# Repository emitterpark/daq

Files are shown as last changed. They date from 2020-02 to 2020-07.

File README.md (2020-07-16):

**DAQ**, Kolaylıkla **IoT (Nesnelerin İnterneti)** projelerinizi
yapabileceğiniz, LoRaWAN kablosuz ağlarıyla uyumlu bir **sensör
aktarıcısıdır**. Üzerindeki **Analog ve Dijital** girişlerine çok
çeşitli sensörleri bağlayabilir, **kilometrelerce** mesafelerden
**kablosuz** yolla bilgi toplayabilirsiniz.

Endüstride mevcut **makineleri** **IoT uyumlu** hale
dönüştürebilirsiniz.

**Akıllı Şehir, Kampüs, Endüstri, Tarım, Otel** ve benzer IoT projenizin
merkezinde **internete** bağlanmış olan bir **LoRaWAN Gateway** cihazı
bulunur. Projenizdeki çok sayıda **DAQ** ünitelerinizden gelen veriler
buradan paketlenerek internete servis edilir. Kendinize ait veya **Açık
kullanım** özelliğindeki diğer kurulu olan LoRaWAN Gateway
cihazlarındanve istasyonlardan faydalanabilirsiniz.

**DAQ** üniteleri, baştan-sona, **The Things Network (TTN)** ve
**myDevices Cayenne** adlı **ücretsiz**

**veri görüntüleme uygulaması** ile tam uyumludur. Uygulamayı indirip
kurduğunuz **PC** ve **Mobil** cihazlarınızda, ünitelerinizden gelen
verileri **zengin görsellerden** takip edebilir, **geçmiş verilere**
erişebilir, **alarm ve uyarıları** bekleyebilirsiniz. Diğer platformlara
kolayca yönlendirebilirsiniz.

LoRaWAN standardı, **ISM** bantlarında, mevcut WiFi, ZigBee, FSK
standartlarına göre daha düşük güçle ve uzak mesafelerde çalışan
kablosuz sensörlerin yapımını mümkün kılar. IP tabanlı olmayıp; **cihaz
kimliği**, uygulama kimliği ve kripto güvenlik anahtarı ile sensörlerin
**IoT platformlarında** takibi için beklenen **esnekliğe ve güvenliğe**
sahiptir.

IoT projeleriniz için **DAQ** ünitelerini, Gateway cihazını ve çeşitli
Analog ve Dijital sensörleri
[[www.example.com]{.ul}](http://www.example.com/) web mağzamızdan satın
alabilirsiniz.

Ürünlerin başlangıç ayarları yapılmış olup **Tak-Çalıştır** özelliği ile
kullanıma hazırdır.

**( Türkiye EU868 MHz )**

**ÖZELLİKLER**

**2 Kanal Analog sensör girişi**

4-20ma endüstriyel otomasyon standardı

Diferansiyel, 16 bit çözünürlük

High ve Low taraf ölçüm yapabilme

Düşük ölçüm direnci, 50 Ohm (Max. 1V gerilim düşümü)

Giriş ölçeklendirme

Sıcaklık, nem, basınç, pozisyon vb. 14 farklı birim tanımlama

Yüksek ve düşük alarm seviyeleri ve kalma süreli histeresis

Aşırı voltaj ve elektrostatik koruma

**2 Kanal Dijital sinyal girişi**

3-24V High seviye

3 farklı dijital birim tanımlama

Dijital alarm ve kalma süreli histeresis

Optoelektronik izolasyon

**5-24V DC endüstriyel besleme girişi**

Dahili 3.3V DC-DC buck dönüştürücü

Alıcı 60mW, Verici 360mW(anlık) güç tüketimi

**Endüstriyel ortama uygun fiziksel tasarım**

Geçmeli tip vidalı klemens girişi

USB micro B konnektör

Aksiyon ledi

Reset butonu

3dbi harici anten

Montaj kulaklı, boyalı alüminyum kutu

24(h)x60(w)x70(l) mm

**Kolay kurulum**

Tak-Çalıştır özelliği, TTN (The Things Network) ve myDevices Cayenne

USB ile PC ve mobil cihazdan parametre ayarlama imkanı

Rapor süresi, alarm seviyeleri, cihaz kimliği, kablosuz çalışma
parametreleri ve diğerleri

**LoRaWAN kablosuz ağ**

LoRaWAN Class A

Lisans gerektirmeyen ISM Bant (EU868, US915, AU915, AS923, IN865, KR920)

20dbm (100mW) radyo verici çıkış gücü

-148dbm radyo alıcı hassasiyeti

Şehir içi 3Km, Şehir dışı 15Km'ye kadar çalışma mesafesi

DevEUI, AppEUI, AppKEY ile OTAA aktivasyonu

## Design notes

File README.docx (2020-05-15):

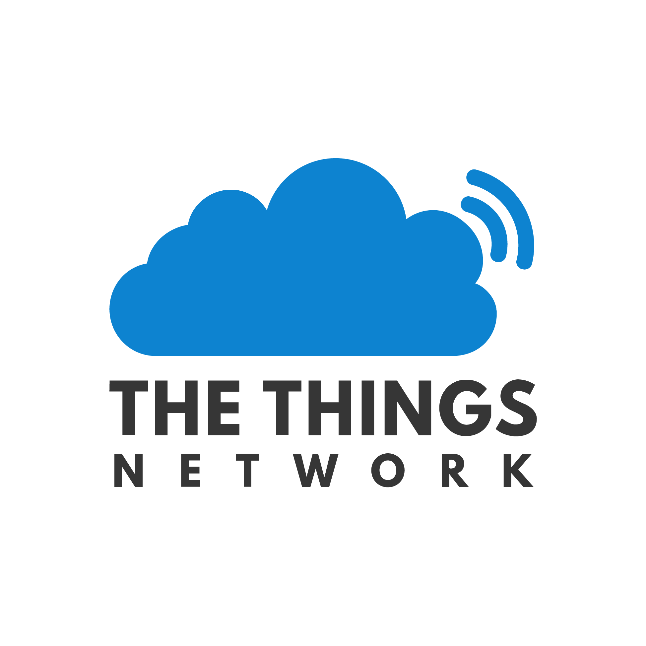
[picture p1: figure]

myDevices

Cayenne

3km Şehir İçi

15km Şehir dışı

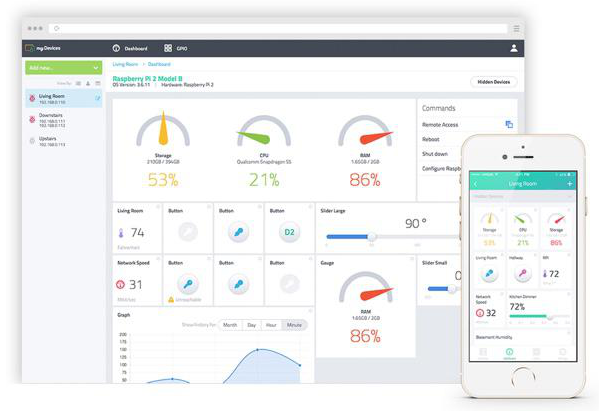
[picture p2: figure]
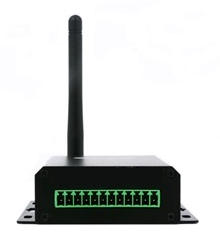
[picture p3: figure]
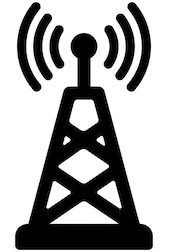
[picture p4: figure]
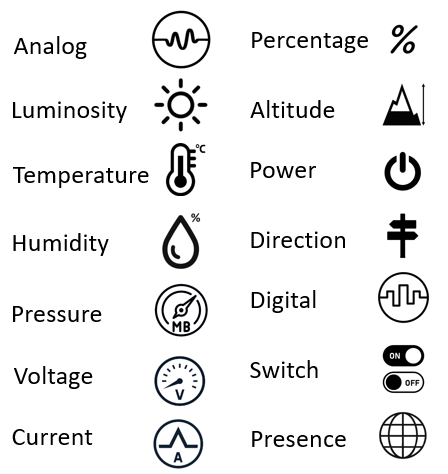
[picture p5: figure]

DAQ

2 X

4-20 ma

Giriş

2 X

Dijital

Giriş

DAQ, Kolaylıkla IoT (Nesnelerin İnterneti) projelerinizi yapabileceğiniz, LoRaWAN kablosuz ağlarıyla uyumlu bir sensör aktarıcısıdır. Üzerindeki Analog ve Dijital girişlerine çok çeşitli sensörleri bağlayabilir, kilometrelerce mesafelerden kablosuz yolla bilgi toplayabilirsiniz.

Endüstride mevcut makineleri IoT uyumlu hale dönüştürebilirsiniz.

Akıllı Şehir, Kampüs, Endüstri, Tarım, Otel ve benzer IoT projenizin merkezinde internete bağlanmış olan bir LoRaWAN Gateway cihazı bulunur. Projenizdeki çok sayıda DAQ ünitelerinizden gelen veriler buradan paketlenerek internete servis edilir. Kendinize ait veya Açık kullanım özelliğindeki diğer kurulu olan LoRaWAN Gateway cihazlarındanve istasyonlardan faydalanabilirsiniz.

DAQ üniteleri, baştan-sona, The Things Network (TTN) ve myDevices Cayenne adlı ücretsiz

veri görüntüleme uygulaması ile tam uyumludur. Uygulamayı indirip kurduğunuz PC ve Mobil cihazlarınızda, ünitelerinizden gelen verileri zengin görsellerden takip edebilir, geçmiş verilere erişebilir, alarm ve uyarıları bekleyebilirsiniz. Diğer platformlara kolayca yönlendirebilirsiniz.

LoRaWAN standardı, ISM bantlarında, mevcut WiFi, ZigBee, FSK standartlarına göre daha düşük güçle ve uzak mesafelerde çalışan kablosuz sensörlerin yapımını mümkün kılar. IP tabanlı olmayıp; cihaz kimliği, uygulama kimliği ve kripto güvenlik anahtarı ile sensörlerin IoT platformlarında takibi için beklenen esnekliğe ve güvenliğe sahiptir.

IoT projeleriniz için DAQ ünitelerini, Gateway cihazını ve çeşitli Analog ve Dijital sensörleri www.example.com web mağzamızdan satın alabilirsiniz.

Ürünlerin başlangıç ayarları yapılmış olup Tak-Çalıştır özelliği ile kullanıma hazırdır.

( Türkiye EU868 MHz )

ÖZELLİKLER

2 Kanal Analog sensör girişi

4-20ma endüstriyel otomasyon standardı

Diferansiyel, 16 bit çözünürlük

High ve Low taraf ölçüm yapabilme

Düşük ölçüm direnci, 50 Ohm (Max. 1V gerilim düşümü)

Giriş ölçeklendirme

Sıcaklık, nem, basınç, pozisyon vb. 14 farklı birim tanımlama

Yüksek ve düşük alarm seviyeleri ve kalma süreli histeresis

Aşırı voltaj ve elektrostatik koruma

2 Kanal Dijital sinyal girişi

3-24V High seviye

3 farklı dijital birim tanımlama

Dijital alarm ve kalma süreli histeresis

Optoelektronik izolasyon

5-24V DC endüstriyel besleme girişi

Dahili 3.3V DC-DC buck dönüştürücü

Alıcı 60mW, Verici 360mW(anlık) güç tüketimi

Endüstriyel ortama uygun fiziksel tasarım

Geçmeli tip vidalı klemens girişi

USB micro B konnektör

Aksiyon ledi

Reset butonu

3dbi harici anten

Montaj kulaklı, boyalı alüminyum kutu

24(h)x60(w)x70(l) mm

Kolay kurulum

Tak-Çalıştır özelliği, TTN (The Things Network) ve myDevices Cayenne

USB ile PC ve mobil cihazdan parametre ayarlama imkanı

Rapor süresi, alarm seviyeleri, cihaz kimliği, kablosuz çalışma parametreleri ve diğerleri

LoRaWAN kablosuz ağ

LoRaWAN Class A

Lisans gerektirmeyen ISM Bant (EU868, US915, AU915, AS923, IN865, KR920)

20dbm (100mW) radyo verici çıkış gücü

-148dbm radyo alıcı hassasiyeti

Şehir içi 3Km, Şehir dışı 15Km’ye kadar çalışma mesafesi

DevEUI, AppEUI, AppKEY ile OTAA aktivasyonu

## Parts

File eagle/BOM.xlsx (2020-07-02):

IC1 | 1 | ATMEGA32U4-MU | QFN-44 |  | X
IC2 | 1 | AP63201WU-7 | SOT23-6 |  | X
IC3,4 | 2 | HCPL-181-00DE (PC357N1–10) | SM MINI FLAT |  | X
IC5,6 | 2 | INA226AIDGS | VSSOP-10 |  | X
MOD1 | 1 | RAK4200 LORA MODULE EU868MHZ | SM-20 | link (https://store.rakwireless.com/products/rak4200-lora-module?variant=31767678091309) | X
D1,2,3,4 | 4 | B5817W | SOD123 |  | X
LED1 | 1 | LED RED 3MM | DIP
XT1 | 1 | CRYSTAL PASSIVE 8MHZ 4PIN | 5032 |  | X
F1 | 1 | PTC RESETTABLE FUSE 0.5A | 1206 |  | X
SW1 | 1 | PUSH BUTTON TACTILE SWITCH 6X6X9MM R/A | DIP | link (https://www.aliexpress.com/item/32901481925.html)
CON1 | 1 | HEADER MALE 2.54MM 6P 2R | DIP
CON2 | 1 | HEADER MALE 2.54MM 8P 2R | DIP
CON3 | 1 | CONNECTOR RF SMA R/A FEMALE 20MM | DIP | link (https://www.aliexpress.com/item/33001356841.html?spm=a2g0o.detail.1000023.2.57702e34zxfXmB)
CON4 | 1 | STANDARD MICRO B USB FEMALE CONNECTOR | SM |  | X
CON5 | 1 | (KF2EDGR)15EDGRC-3.81-10P (HEADER RA) + (KF2EDGK)15EDGK-3.81-10P (PLUG) | DIP
L1 | 1 | CDRH127R 10UH INDUCTOR 12X12MM SHIELDED | SM
L2,3 | 2 | MMZ2012Y152B FERRITE BEAD | 0805 |  | X ?????
C1,8,21,22,27,32 | 6 | 10UF X5R/X7R | 0603 |  | X
C2,5,7,10,12,15,16,18,19,20,23,24,25,26,31 | 15 | 100NF X5R/X7R | 0603 |  | X
C3,4 | 2 | 22PF X5R/X7R | 0603 |  | X
C6,28,29,30,33,34,35 | 7 | 1UF X5R/X7R | 0603 |  | X
C9,13,14 | 3 | 22UF X7R | 1206 |  | X
C11 | 1 | 100PF X5R/X7R | 0603 |  | X
C17 | 1 | 100UF 8MM | SM |  | X
R1,2 | 2 | 22R 5% | 0603 |  | X
R3,8,10,12,14,16,17,22,27,28 | 10 | 10K 5% | 0603 |  | X
R4 | 1 | 220R 5% | 0603 |  | X
R5 | 1 | 115K 1% (120K) (110K) | 0603 |  | X
R6 | 1 | 33K 1% (36K) (33K) | 0603 |  | X
R7,9,11 | 3 | 100R 5% | 0603 |  | X
R13,15 | 2 | 2K2 5% | 0805 |  | X
R18,23 | 2 | 3.9R 1% | 0805 |  | X
R19,20,24,25 | 4 | 50R 1% | 0805 |  | X ?????
R21,26 | 2 | 10R 5% | 0603 |  | X
ANTENNA | 1 | 868MHZ 5DBI SMA-MALE WHIP |  | link (https://www.aliexpress.com/item/32921464471.html?spm=2114.12010612.8148356.36.3e3f1f0b2ckfAt)
ALUMINUM ENCLOSURE | 1 | AK-C-A16 24(H)X80(W)X90(L) MM CUSTOM 68.7(L) MM |  | link (https://www.aliexpress.com/item/1585694309.html)
PCB | 1 | FR4 1.6MM 1ozCu 59.7(W)X68.6(L) MM (2350X2700MIL)
LAZER CUTTING

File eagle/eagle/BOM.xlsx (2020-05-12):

IC1 | 1 | ATMEGA32U4-MU | QFN-44
IC2 | 1 | AP63201WU-7 | SOT23-6 | AP63200 OLD
IC3,4 | 2 | HCPL-181-00DE (PC357N1–10) | SM MINI FLAT | link (https://www.aliexpress.com/item/32909119073.html?spm=2114.12010615.8148356.4.657bf361XrP6RL)
IC5,6 | 2 | INA226AIDGS | VSSOP-10 | link (http://www.aliexpress.com/item/33021667752.html?spm=2114.12010615.8148356.2.31ef2adf4GEmzi)
MOD1 | 1 | RAK4200 LORA MODULE EU868MHZ | SM-20 | link (https://store.rakwireless.com/products/rak4200-lora-module?variant=31767678091309)
D1,2,3,4 | 4 | B5817W | SOD123 | REFERENCE
LED1 | 1 | LED RED 3MM | DIP
XT1 | 1 | CRYSTAL PASSIVE 8MHZ 4PIN | 5032 | link (https://www.aliexpress.com/item/33010692278.html?spm=2114.12010615.8148356.8.e30c5802x90R2k)
F1 | 1 | PTC RESETTABLE FUSE 0.5A | 1206 | link (https://www.aliexpress.com/item/32876140005.html?spm=2114.12010615.8148356.3.5236158aukLNWK)
SW1 | 1 | PUSH BUTTON TACTILE SWITCH 6X6X9MM R/A | DIP | link (https://www.aliexpress.com/item/32901481925.html)
CON1 | 1 | HEADER MALE 2.54MM 6P 2R | DIP
CON2 | 1 | HEADER MALE 2.54MM 8P 2R | DIP
CON3 | 1 | CONNECTOR RF SMA R/A EOCT-WF1320 57001579 | DIP | link (https://www.aliexpress.com/item/33050835786.html)
CON4 | 1 | STANDARD MICRO B USB FEMALE CONNECTOR | SM
CON5 | 1 | (KF2EDGR)15EDGRC-3.81-10P (HEADER RA) + (KF2EDGK)15EDGK-3.81-10P (PLUG) | DIP
L1 | 1 | CDRH127R 6.8UH INDUCTOR 12X12MM SHIELDED | SM
L2,3 | 2 | MMZ2012Y152B FERRITE BEAD | 0805 | (150R @100MHZ) REFERENCE
C1,8,21,22,27,30 | 5 | 10UF X5R/X7R | 0603
C2,5,7,10,12,15,16,18,19,20,23,24,25,26,28,29,31 | 12 | 100NF X5R/X7R | 0603
C3,4 | 2 | 22PF X5R/X7R | 0603
C6, | 3 | 1UF X5R/X7R | 0603
C9,13,14 | 3 | 22UF X7R | 1206
C11 | 1 | 100PF X5R/X7R | 0603
C17 | 1 | 100UF 8MM | SM
R1,2 | 2 | 22R 5% | 0603
R3,8,10,12,14,16,17,24,31,32 | 10 | 10K 5% | 0603
R4 | 1 | 220R 5% | 0603
R5 | 1 | 115K 1% (120K) (110K) | 0603
R6 | 1 | 33K 1% (36K) (33K) | 0603
R7,9,11 | 3 | 100R 5% | 0603
R13,15 | 2 | 2K2 5% | 0805
R18,20,25,27 | 4 | 10R 1% | 0603
R19,26 | 2 | 3.3R 1% | 0805
R21,22,28,29 | 4 | 50R 1% | 0805
R23,30 | 2 | 10R 5% | 0603
ANTENNA | 1 | 868MHZ 5DBI SMA-MALE WHIP |  | link (https://www.aliexpress.com/item/32921464471.html?spm=2114.12010612.8148356.36.3e3f1f0b2ckfAt)
ALUMINUM ENCLOSURE | 1 | AK-C-A16 24(H)X80(W)X90(L) MM COLOR BLUE CUSTOM 68.7(L) MM |  | angie@szomk.com.cn
PCB | 1 | FR4 1.6MM 1ozCu 59.7(W)X65.4(L) MM (2350X2575MIL)

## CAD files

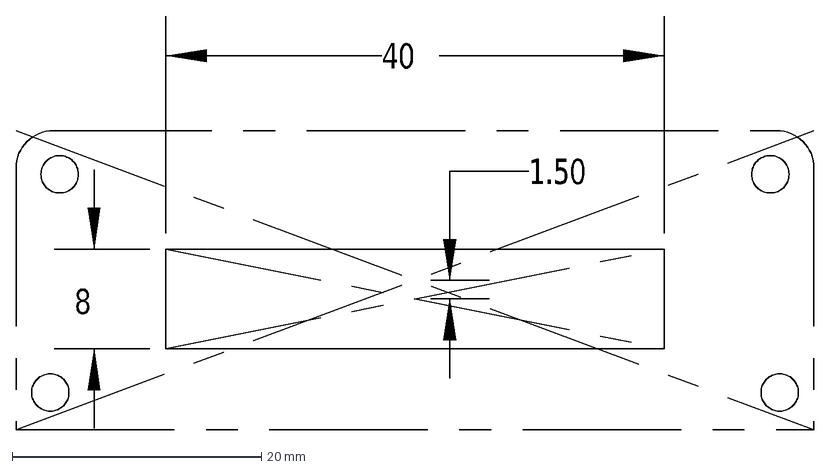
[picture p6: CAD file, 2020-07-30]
physical/eng/rear panel.DXF
1.50
40
8

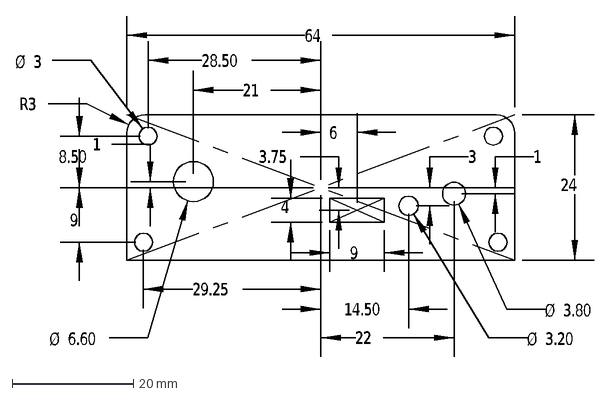
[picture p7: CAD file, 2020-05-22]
physical/ön kapak.DXF
64
24
21
1
Ø
6.60
3.20
14.50
3
3.80
22
3.75
6
9
4
R3
28.50
8.50
29.25

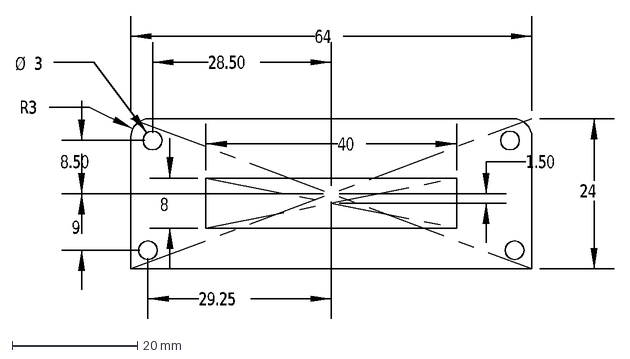
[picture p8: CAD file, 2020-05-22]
physical/arka kapak.DXF
64
24
R3
28.50
8.50
29.25
9
Ø
3
1.50
40
8

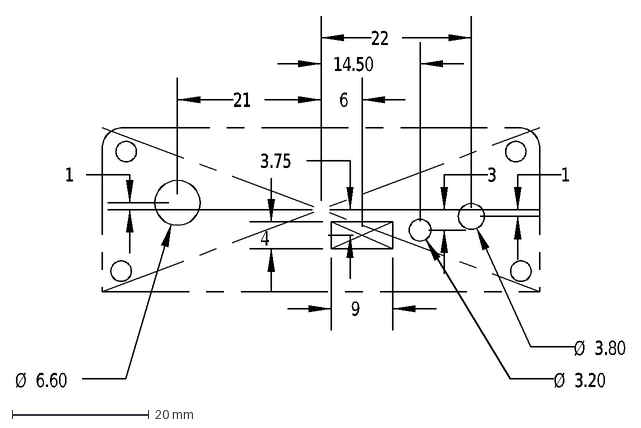
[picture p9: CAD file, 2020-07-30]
physical/eng/front panel.DXF
21
1
Ø
6.60
3.20
14.50
3
3.80
22
3.75
6
9
4

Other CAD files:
physical/arka kapak.DWG
physical/arka kapak.SLDDRW
physical/eng/front panel.DWG
physical/eng/front panel.SLDDRW
physical/eng/rear panel.DWG
physical/eng/rear panel.SLDDRW
physical/ön kapak.DWG
physical/ön kapak.SLDDRW

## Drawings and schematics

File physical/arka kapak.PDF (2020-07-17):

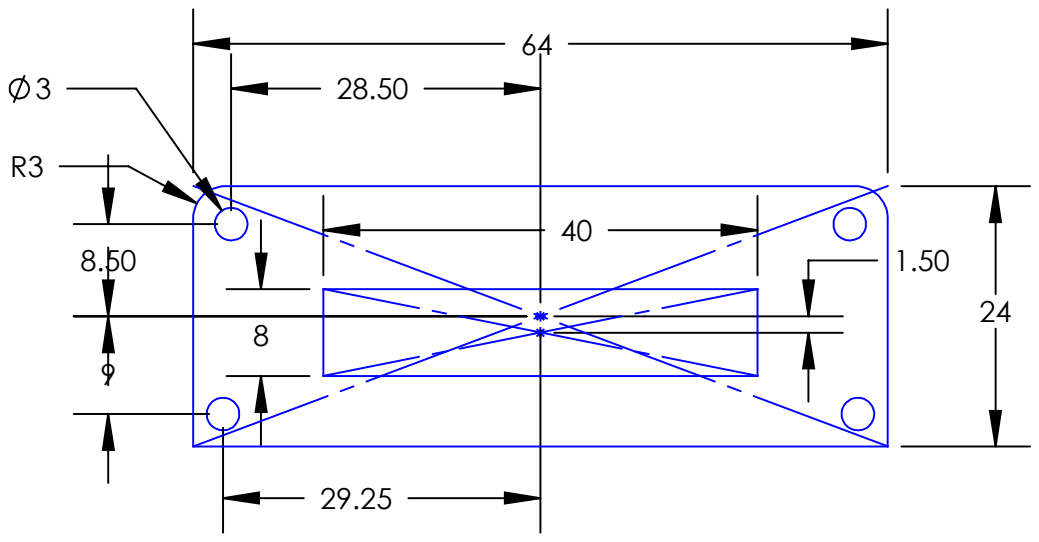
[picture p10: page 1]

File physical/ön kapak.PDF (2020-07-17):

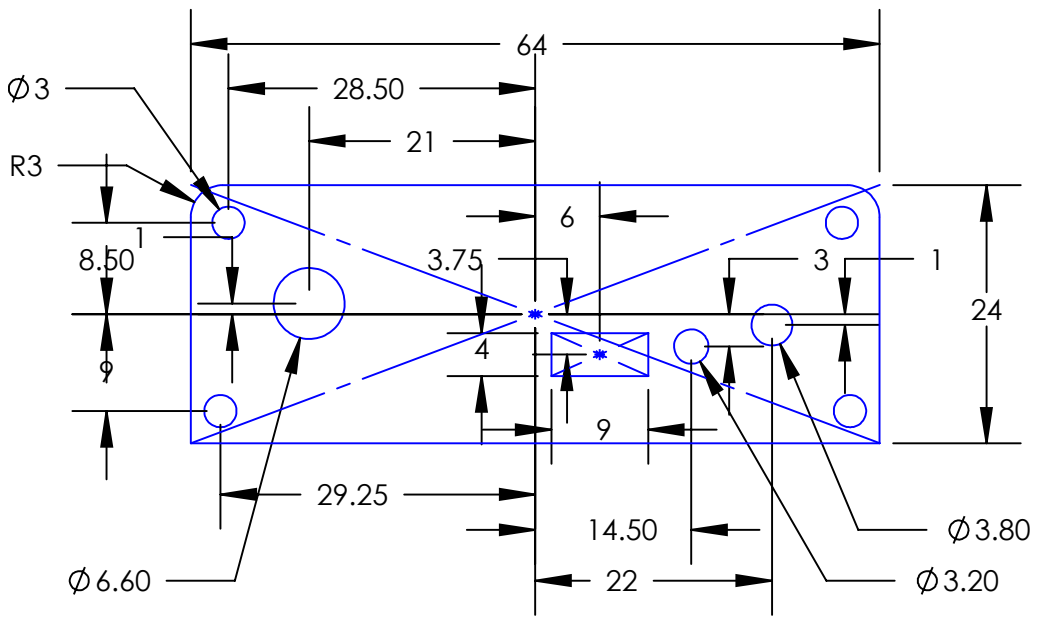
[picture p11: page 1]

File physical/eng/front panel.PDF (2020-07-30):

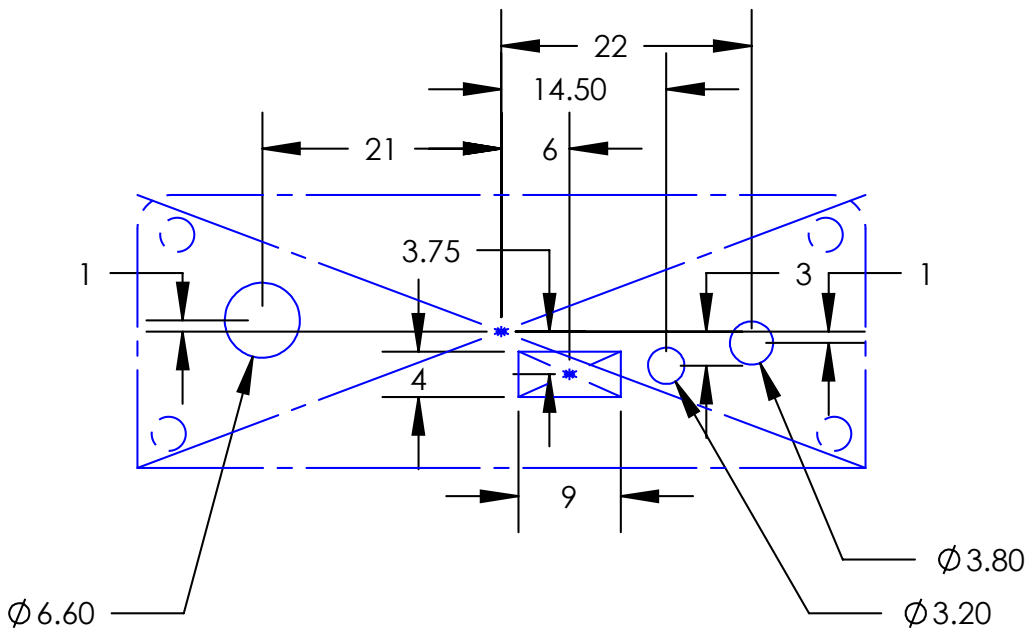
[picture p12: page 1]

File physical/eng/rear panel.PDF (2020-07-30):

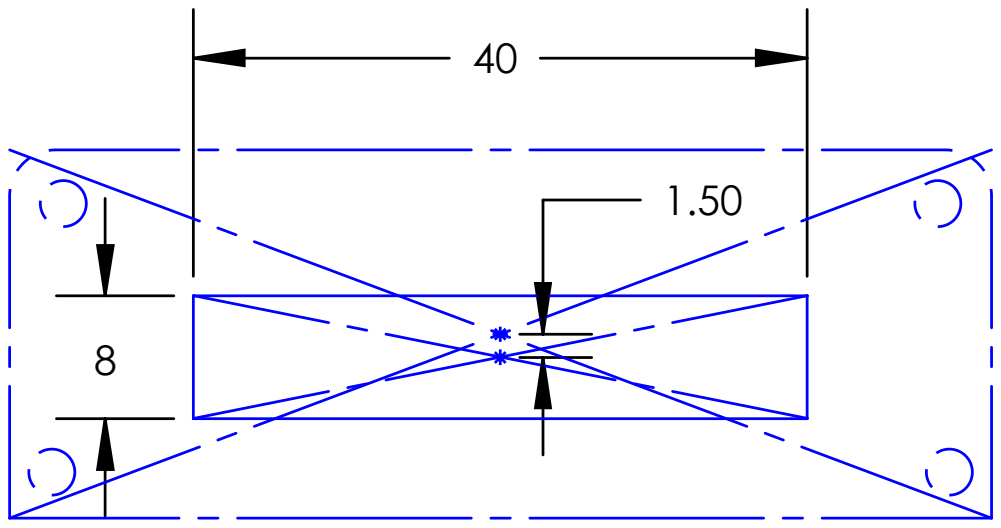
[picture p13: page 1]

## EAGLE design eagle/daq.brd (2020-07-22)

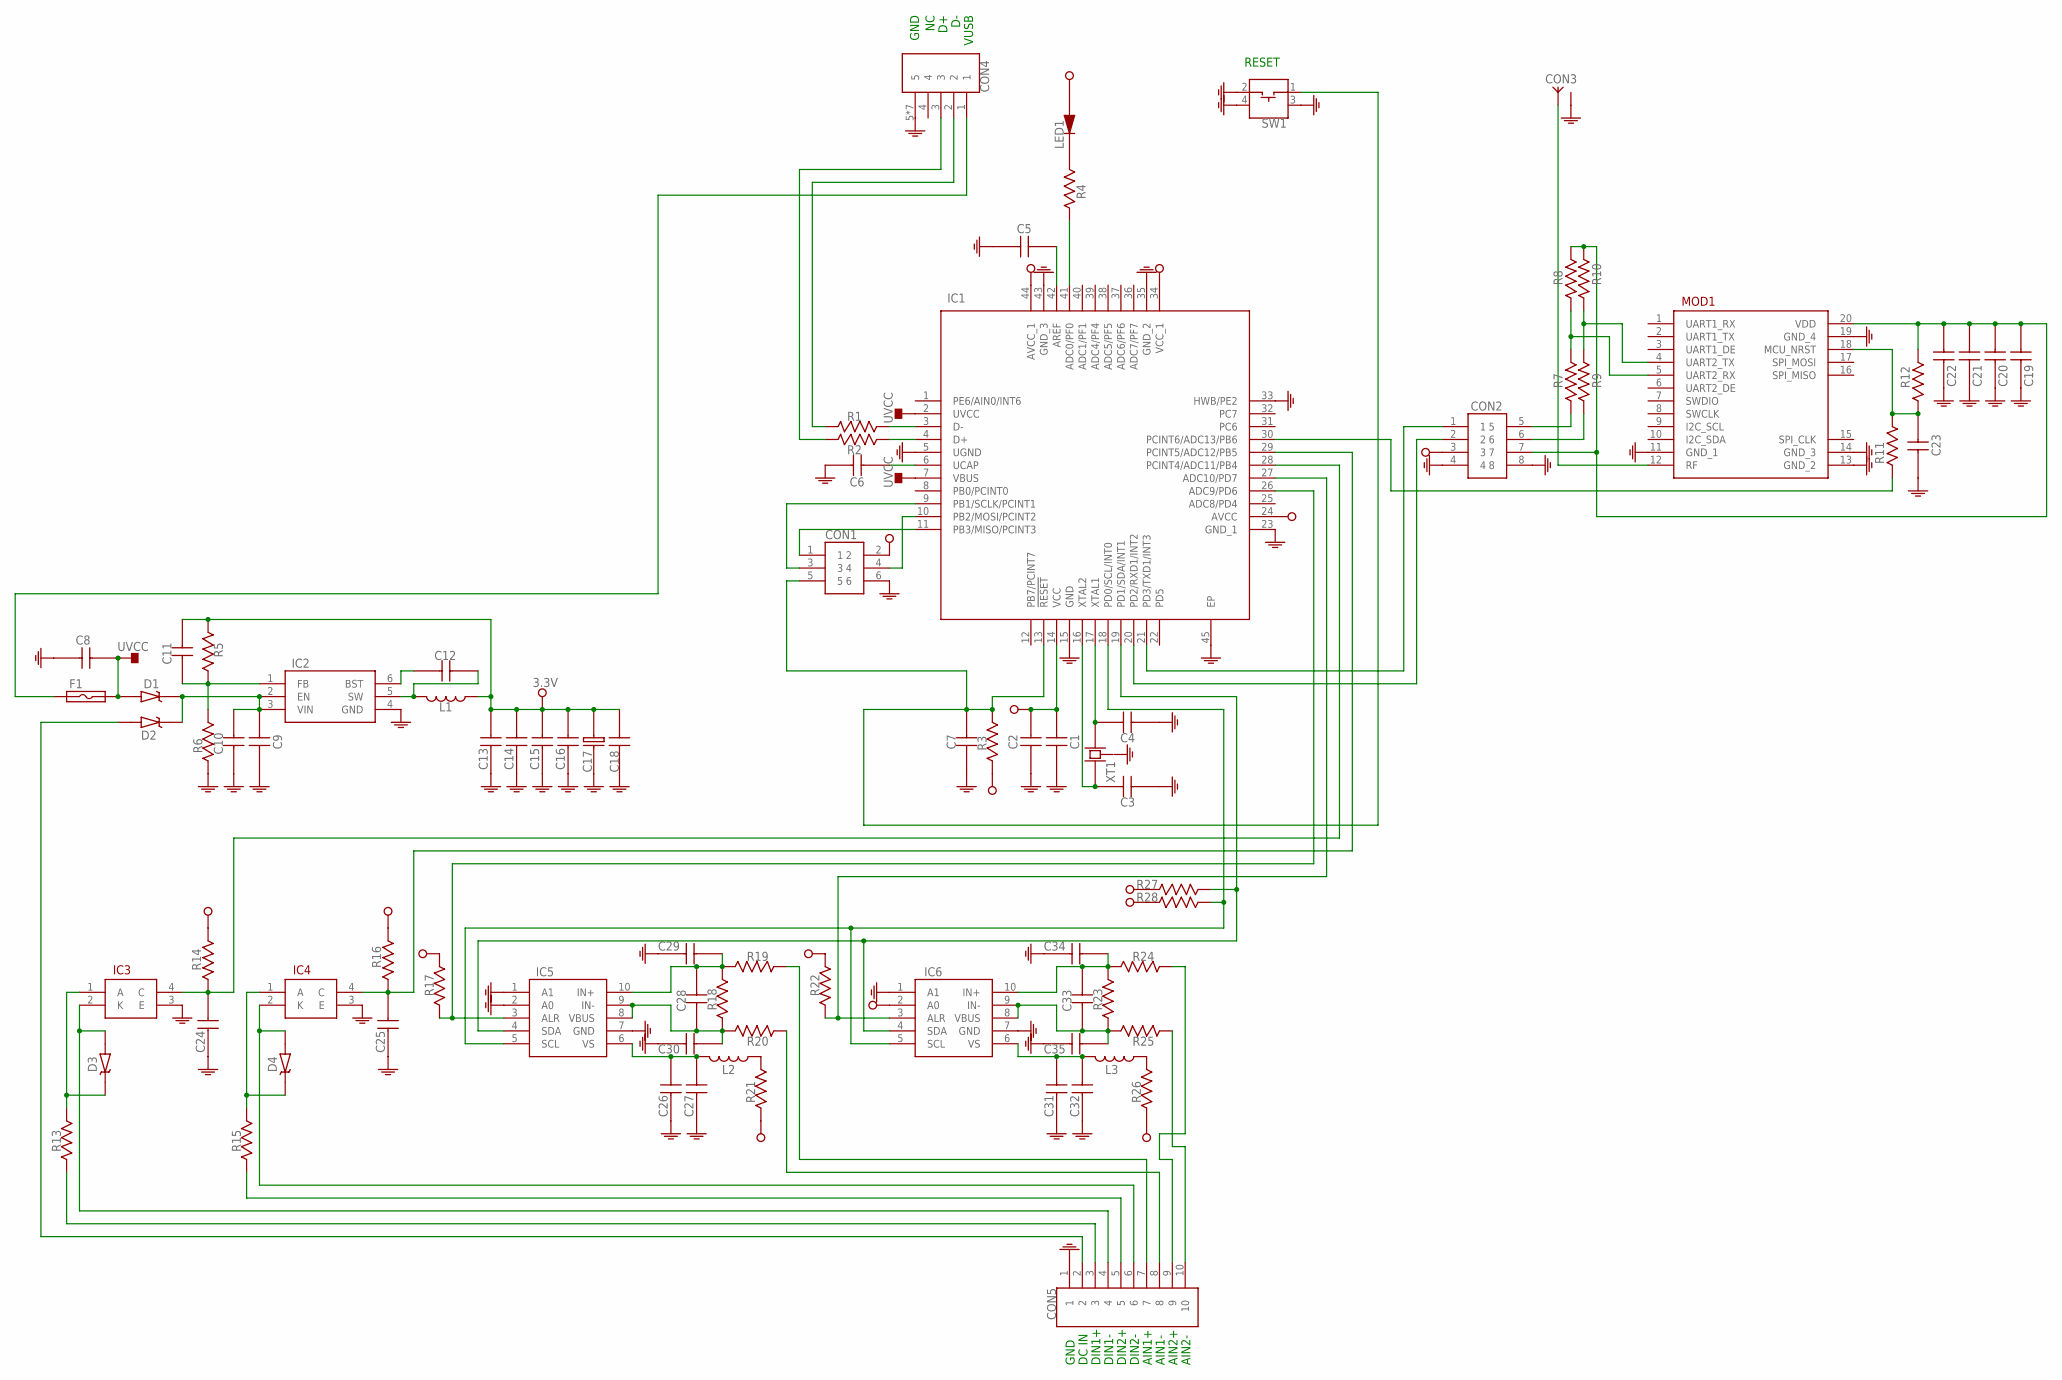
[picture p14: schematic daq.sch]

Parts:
C1, C2, C3, C4, C5, C6, C7, C8, C10, C11, C12, C15, C16, C18, C19, C20, C21, C22, C23, C24, C25, C26, C27, C28, C29, C30, C31, C32, C33, C34, C35: CAPACITOR-0603; 0603
C9, C13, C14: CAPACITOR-1206; 1206
C17: CAPACITOR-SMD-8
CON1: ISP
CON2: HEADER-8P-2R-DIP-2_54MM
CON3: SMA-RF
CON4: USB-MICRO-B-SMD
CON5: 15EDGRC-3.81-10P
D1, D2, D3, D4: DIODE-SCHOTTKY; SOD123-DIODE
F1: FUSE-1206; 1206
IC1: ATMEGA32U4-MU; QFN-44
IC2: AP63200; SOT23-6
IC3, IC4: OPTO-SMD
IC5, IC6: INA226; VSSOP-10
L1: INDUCTOR-CDRH127R
L2, L3: INDUCTOR-0805; 0805
LED1: LED-3MM-RA
MOD1: RAK4200
R1, R2, R3, R4, R5, R6, R7, R8, R9, R10, R11, R12, R14, R16, R17, R21, R22, R26, R27, R28: RESISTOR-0603; 0603
R13, R15, R18, R19, R20, R23, R24, R25: RESISTOR-0805; 0805
SW1: B3F-3150-52-55
XT1: CRYSTAL-5032-4P

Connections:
GND: C1.1, C2.1, C3.1, C4.1, C5.1, C6.1, C7.1, C8.1, C9.1, C10.1, C13.1, C14.1, C15.1, C16.1, C17.1, C18.1, C19.1, C20.1, C21.1, C22.1, C23.1, C24.1, C25.1, C26.1, C27.1, C29.2, C30.2, C31.1, C32.1, C34.2, C35.2, CON1.6, CON2.4, CON2.8, CON3.2 (GND), CON3.3 (GND), CON3.4 (GND), CON3.5 (GND), CON4.5, CON4.6 (5), CON4.7 (5), CON4.8 (5), CON4.9 (5), CON4.10 (5), CON4.11 (5), CON5.1, IC1.5 (UGND), IC1.15 (GND), IC1.23 (GND_1), IC1.33 (HWB/PE2), IC1.35 (GND_2), IC1.43 (GND_3), IC1.45 (EP), IC2.4 (GND), IC3.3 (E), IC4.3 (E), IC5.1 (A1), IC5.2 (A0), IC5.7 (GND), IC6.1 (A1), IC6.7 (GND), MOD1.11 (GND_1), MOD1.13 (GND_2), MOD1.14 (GND_3), MOD1.19 (GND_4), R6.1, SW1.2, SW1.3, SW1.4, XT1.2 (GND), XT1.4 (GND)
unnamed: IC1.41 (ADC0/PF0), R4.1
unnamed: C23.2, MOD1.18 (MCU_NRST), R11.1, R12.1
unnamed: CON1.1, IC1.11 (PB3/MISO/PCINT3)
unnamed: CON3.1 (ANT), MOD1.12 (RF)
unnamed: C28.1, C30.1, IC5.8 (VBUS), IC5.9 (IN-), R18.1, R20.2
unnamed: MOD1.5 (UART2_RX), R7.2, R8.1
unnamed: CON5.2, D2.2 (A)
unnamed: C33.1, C35.1, IC6.8 (VBUS), IC6.9 (IN-), R23.1, R25.2
unnamed: CON1.4, IC1.10 (PB2/MOSI/PCINT2)
unnamed: C3.2, IC1.16 (XTAL2), XT1.1
unnamed: C28.2, C29.1, IC5.10 (IN+), R18.2, R19.2
unnamed: C4.2, IC1.17 (XTAL1), XT1.3 (2)
unnamed: C19.2, C20.2, C21.2, C22.2, CON2.7, MOD1.20 (VDD), R8.2, R10.2, R12.2
unnamed: CON2.5, R7.1
unnamed: IC1.27 (ADC10/PD7), IC6.3 (ALR), R22.2
unnamed: CON2.6, R9.1
unnamed: CON4.2, R1.1
unnamed: CON4.3, R2.1
unnamed: D3.1 (K), IC3.1 (A), R13.2
unnamed: IC1.30 (PCINT6/ADC13/PB6), R11.2
unnamed: IC1.26 (ADC9/PD6), IC5.3 (ALR), R17.2
unnamed: CON2.1, IC1.21 (PD3/TXD1/INT3)
unnamed: CON2.2, IC1.20 (PD2/RXD1/INT2)
unnamed: LED1.K, R4.2
unnamed: L3.1, R26.2
unnamed: CON5.8, R20.1
unnamed: CON5.7, R19.1
unnamed: CON5.10, R25.1
unnamed: C5.2, IC1.42 (AREF)
unnamed: C25.2, IC1.29 (PCINT5/ADC12/PB5), IC4.4 (C), R16.2
unnamed: D4.1 (K), IC4.1 (A), R15.2
unnamed: C6.2, IC1.6 (UCAP)
unnamed: C24.2, IC1.28 (PCINT4/ADC11/PB4), IC3.4 (C), R14.2
unnamed: CON5.9, R24.1
unnamed: MOD1.4 (UART2_TX), R9.2, R10.1
unnamed: C33.2, C34.1, IC6.10 (IN+), R23.2, R24.2
unnamed: C7.2, CON1.5, IC1.13 (!RESET), R3.2, SW1.1
unnamed: C31.2, C32.2, IC6.6 (VS), L3.2
unnamed: IC1.3 (D-), R1.2
unnamed: IC1.4 (D+), R2.2
unnamed: CON1.3, IC1.9 (PB1/SCLK/PCINT1)
unnamed: CON5.6, D4.2 (A), IC4.2 (K)
unnamed: CON5.4, D3.2 (A), IC3.2 (K)
unnamed: CON5.5, R15.1
unnamed: CON4.1, F1.1
unnamed: C9.2, C10.2, D1.1 (K), D2.1 (K), IC2.2 (EN), IC2.3 (VIN)
unnamed: C12.2, IC2.6 (BST)
unnamed: C12.1, IC2.5 (SW), L1.2
unnamed: L2.1, R21.2
unnamed: C11.1, IC2.1 (FB), R5.2, R6.2
unnamed: IC1.18 (PD0/SCL/INT0), IC5.5 (SCL), IC6.5 (SCL), R28.2
unnamed: C26.2, C27.2, IC5.6 (VS), L2.2
unnamed: IC1.19 (PD1/SDA/INT1), IC5.4 (SDA), IC6.4 (SDA), R27.2
unnamed: CON5.3, R13.1
UVCC: C8.2, D1.2 (A), F1.2, IC1.2 (UVCC), IC1.7 (VBUS)
VCC: C1.2, C2.2, C11.2, C13.2, C14.2, C15.2, C16.2, C17.2, C18.2, CON1.2, CON2.3, IC1.14 (VCC), IC1.24 (AVCC), IC1.34 (VCC_1), IC1.44 (AVCC_1), IC6.2 (A0), L1.1, LED1.A, R3.1, R5.1, R14.1, R16.1, R17.1, R21.1, R22.1, R26.1, R27.1, R28.1

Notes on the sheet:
DC IN
GND
AIN1+
AIN1-
AIN2+
AIN2-
DIN1+
DIN1-
DIN2+
DIN2-
VUSB
RESET

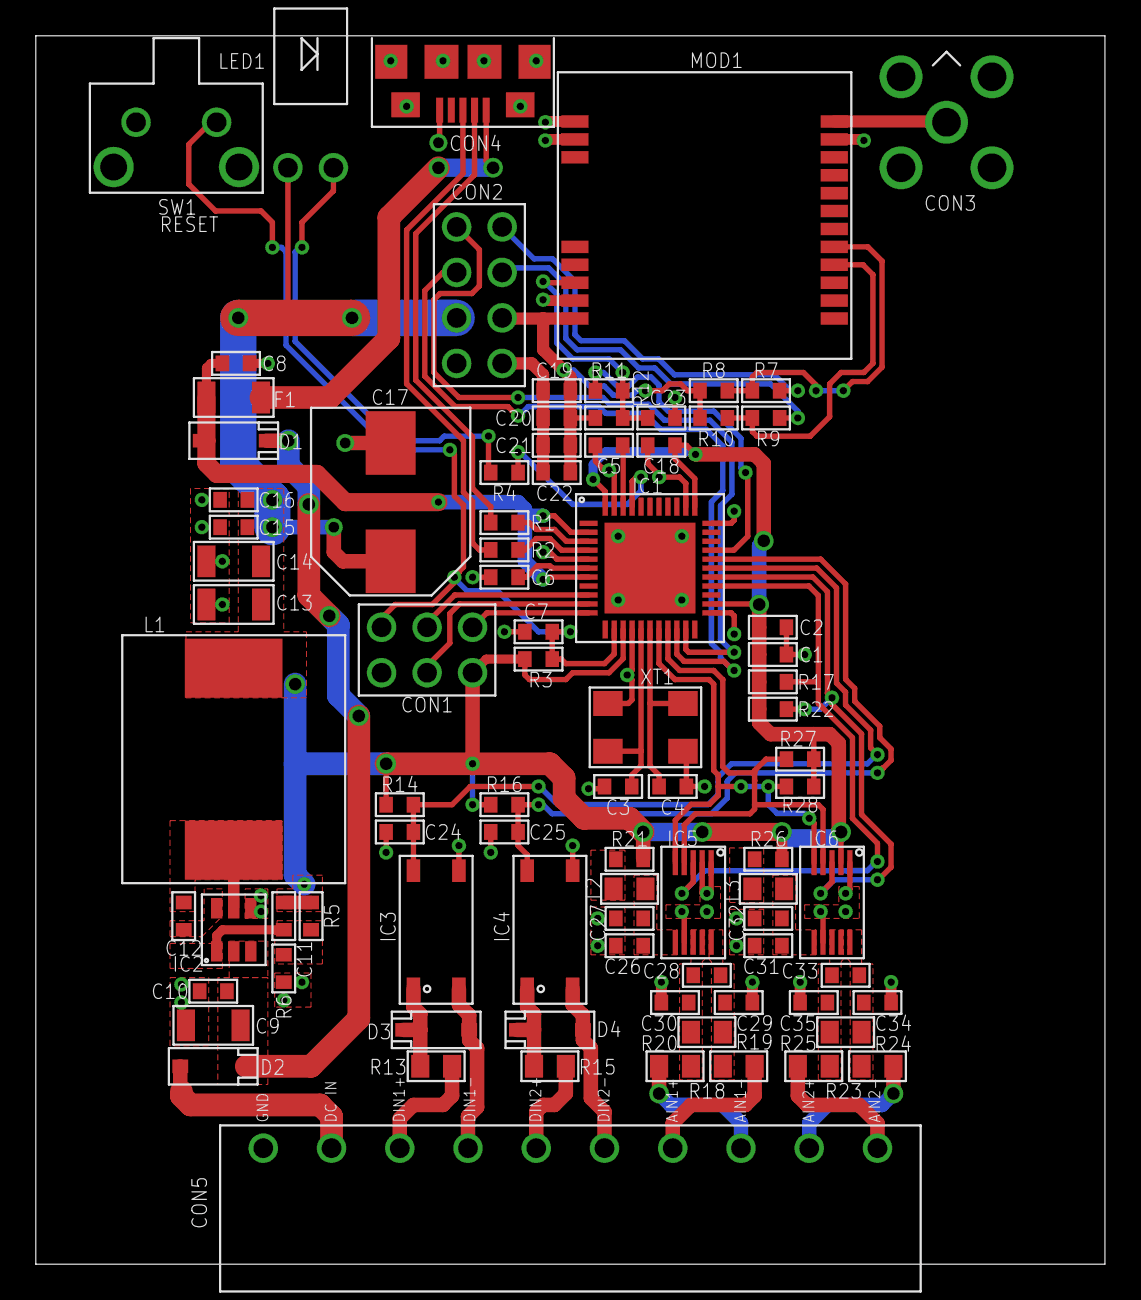
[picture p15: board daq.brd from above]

Board: 2 copper layers, 59.7 x 68.6 mm, 86 parts (0 on the bottom side), 57 nets.

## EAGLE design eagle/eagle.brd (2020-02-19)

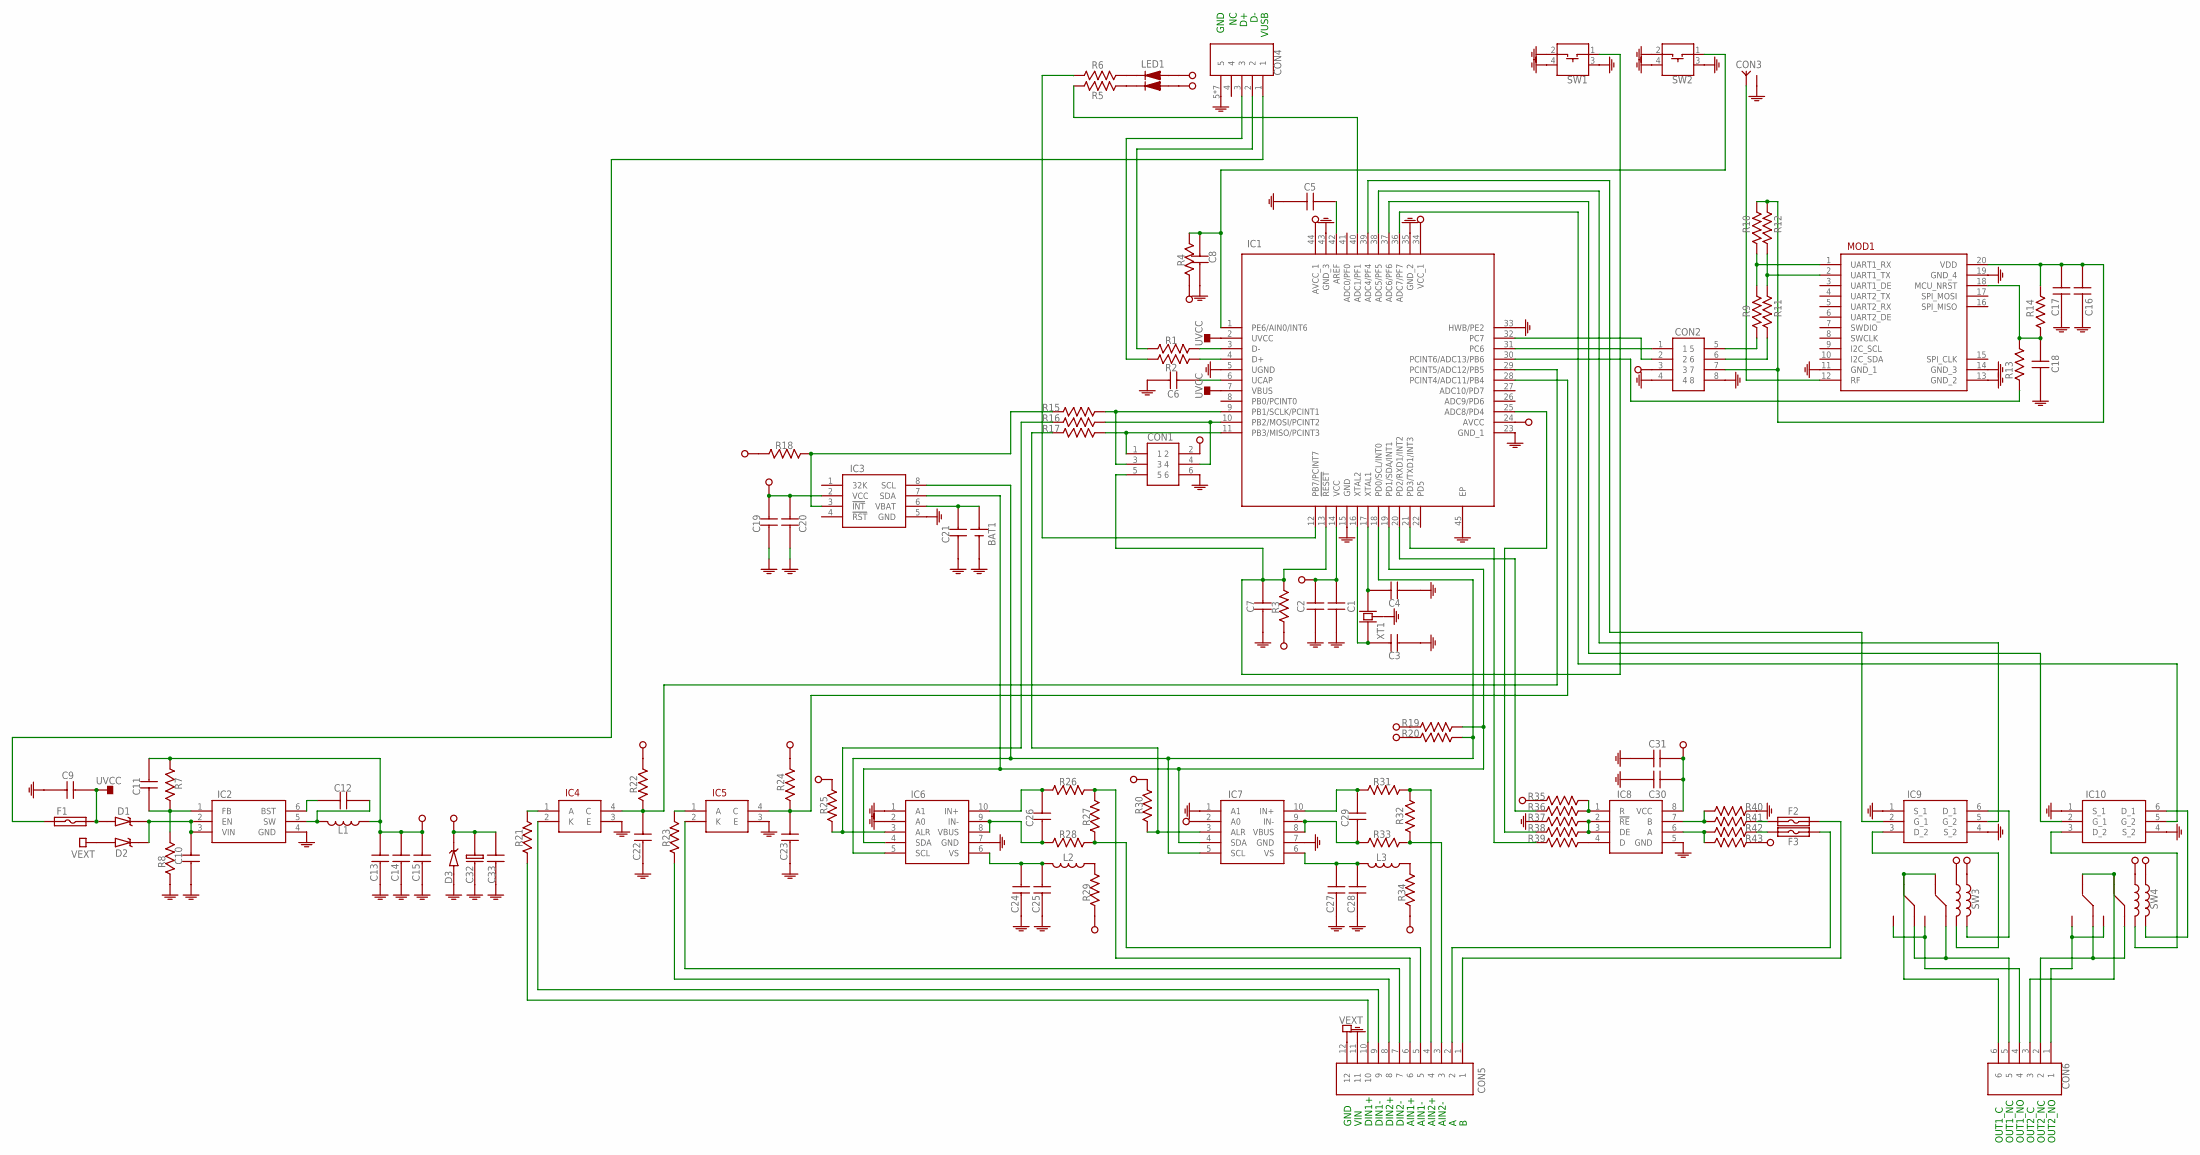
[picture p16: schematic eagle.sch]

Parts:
BAT1: BAT-1220-BC501SM
C1, C2, C3, C4, C5, C6, C7, C8, C9, C11, C12, C15, C16, C17, C18, C19, C20, C21, C22, C23, C24, C25, C26, C27, C28, C29, C30, C31, C33: CAPACITOR-0603; 0603
C10, C13, C14: CAPACITOR-1206; 1206
C32: CAPACITOR-SMD-8
CON1: ISP
CON2: HEADER-8P-2R-DIP-2_54MM
CON3: SMA-RF
CON4: USB-MICRO-B-SMD
CON5: KF2EDGR-3.5-12P
CON6: KF2EDGR-3.5-6P
D1, D2: DIODE-SCHOTTKY; SOD123-DIODE
D3: ZENER-SOD123; SOD123-DIODE
F1, F2, F3: FUSE-1206; 1206
IC1: ATMEGA32U4-MU; QFN-44
IC2: AP63200; SOT23-6
IC3: DS3231M; SOIC-8
IC4, IC5: OPTO-SMD
IC6, IC7: INA226; VSSOP-10
IC8: IC-485-HALF; SOIC-8
IC9, IC10: NUD3105-12-24-60; SC74-6
L1: INDUCTOR-0520-0630
L2, L3: INDUCTOR-0805; 0805
LED1: LED-HOLDER-2P
MOD1: RAK4200
R1, R2, R3, R4, R5, R6, R7, R8, R9, R10, R11, R12, R13, R14, R15, R16, R17, R18, R19, R20, R22, R24, R25, R26, R28, R29, R30, R31, R33, R34, R35, R36, R37, R38, R39, R40, R43: RESISTOR-0603; 0603
R21, R23, R41, R42: RESISTOR-0805; 0805
R27, R32: RESISTOR-1206; 1206
SW1, SW2: B3F-3150-52-55
SW3, SW4: HFD2-L2
XT1: CRYSTAL-5032-4P

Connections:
GND: BAT1.-, C1.1, C2.1, C3.1, C4.1, C5.1, C6.1, C7.1, C8.2, C9.1, C10.1, C13.1, C14.1, C15.1, C16.1, C17.1, C18.1, C19.1, C20.1, C21.1, C22.1, C23.1, C24.1, C25.1, C27.1, C28.1, C30.1, C31.1, C32.1, C33.1, CON1.6, CON2.4, CON2.8, CON3.2 (GND), CON3.3 (GND), CON3.4 (GND), CON3.5 (GND), CON4.5, CON4.6 (5), CON4.7 (5), CON4.8 (5), CON4.9 (5), CON4.10 (5), CON4.11 (5), CON5.11, D3.2 (A), IC1.5 (UGND), IC1.15 (GND), IC1.23 (GND_1), IC1.33 (HWB/PE2), IC1.35 (GND_2), IC1.43 (GND_3), IC1.45 (EP), IC2.4 (GND), IC3.5 (GND), IC4.3 (E), IC5.3 (E), IC6.1 (A1), IC6.2 (A0), IC6.7 (GND), IC7.1 (A1), IC7.7 (GND), IC8.5 (GND), IC9.1 (S_1), IC9.4 (S_2), IC10.1 (S_1), IC10.4 (S_2), MOD1.11 (GND_1), MOD1.13 (GND_2), MOD1.14 (GND_3), MOD1.19 (GND_4), R8.1, R37.1, R40.1, SW1.2, SW1.3, SW1.4, SW2.2, SW2.3, SW2.4, XT1.2 (GND), XT1.4 (GND)
unnamed: IC1.40 (ADC1/PF1), R5.1
unnamed: C18.2, MOD1.18 (MCU_NRST), R13.1, R14.1
unnamed: CON1.1, IC1.11 (PB3/MISO/PCINT3), R17.2
unnamed: CON3.1 (ANT), MOD1.12 (RF)
unnamed: CON2.2, IC1.32 (PC7)
unnamed: MOD1.1 (UART1_RX), R9.2, R10.1
unnamed: MOD1.2 (UART1_TX), R11.2, R12.1
unnamed: LED1.1 (K1), R6.2
unnamed: CON1.4, IC1.10 (PB2/MOSI/PCINT2), R16.2
unnamed: C3.2, IC1.16 (XTAL2), XT1.1
unnamed: CON2.1, IC1.31 (PC6)
unnamed: C4.2, IC1.17 (XTAL1), XT1.3 (2)
unnamed: C16.2, C17.2, CON2.7, MOD1.20 (VDD), R10.2, R12.2, R14.2
unnamed: CON2.5, R9.1
unnamed: LED1.3 (K2), R5.2
unnamed: CON2.6, R11.1
unnamed: C29.1, IC7.8 (VBUS), IC7.9 (IN-), R33.2
unnamed: CON4.2, R1.1
unnamed: CON4.3, R2.1
unnamed: IC4.1 (A), R21.2
unnamed: C29.2, IC7.10 (IN+), R31.2
unnamed: IC1.30 (PCINT6/ADC13/PB6), R13.2
unnamed: IC6.3 (ALR), R16.1, R25.2
unnamed: IC1.36 (ADC7/PF7), IC10.5 (G_2)
unnamed: IC7.3 (ALR), R17.1, R30.2
unnamed: IC9.6 (D_1), SW3.L1-
unnamed: L3.1, R34.2
unnamed: IC9.3 (D_2), SW3.L2-
unnamed: C8.1, IC1.1 (PE6/AIN0/INT6), R4.1, SW2.1
unnamed: CON5.4, R31.1, R32.1
unnamed: C5.2, IC1.42 (AREF)
unnamed: C23.2, IC1.28 (PCINT4/ADC11/PB4), IC5.4 (C), R24.2
unnamed: IC5.1 (A), R23.2
unnamed: C6.2, IC1.6 (UCAP)
unnamed: C22.2, IC1.29 (PCINT5/ADC12/PB5), IC4.4 (C), R22.2
unnamed: IC1.12 (PB7/PCINT7), R6.1
unnamed: IC1.37 (ADC6/PF6), IC10.2 (G_1)
unnamed: CON6.1, SW4.NO1, SW4.NO2
unnamed: CON5.3, R32.2, R33.1
unnamed: C7.2, CON1.5, IC1.13 (!RESET), R3.2, SW1.1
unnamed: C27.2, C28.2, IC7.6 (VS), L3.2
unnamed: IC1.3 (D-), R1.2
unnamed: IC1.4 (D+), R2.2
unnamed: CON1.3, IC1.9 (PB1/SCLK/PCINT1), R15.2
unnamed: CON5.2, F3.1
unnamed: IC8.1 (R), R35.2, R36.2
unnamed: IC8.4 (D), R39.2
unnamed: CON5.7, IC5.2 (K)
unnamed: CON5.9, IC4.2 (K)
unnamed: IC8.7 (B), R40.2, R41.2
unnamed: IC8.6 (A), R42.2, R43.2
unnamed: IC8.2 (!RE), IC8.3 (DE), R37.2, R38.2
unnamed: F3.2, R42.1
unnamed: CON5.8, R23.1
unnamed: CON4.1, F1.1
unnamed: C10.2, D1.1 (K), D2.1 (K), IC2.2 (EN), IC2.3 (VIN)
unnamed: BAT1.+, C21.2, IC3.6 (VBAT)
unnamed: CON5.6, R26.2, R27.2
unnamed: CON5.1, F2.1
unnamed: IC1.20 (PD2/RXD1/INT2), R36.1
unnamed: IC1.21 (PD3/TXD1/INT3), R39.1
unnamed: IC1.25 (ADC8/PD4), R38.1
unnamed: IC10.6 (D_1), SW4.L1-
unnamed: C12.2, IC2.6 (BST)
unnamed: C12.1, IC2.5 (SW), L1.2
unnamed: CON6.2, SW4.NC1, SW4.NC2
unnamed: C26.2, IC6.10 (IN+), R26.1
unnamed: C26.1, IC6.8 (VBUS), IC6.9 (IN-), R28.1
unnamed: IC3.3 (!INT), R15.1, R18.2
unnamed: L2.1, R29.2
unnamed: C11.1, IC2.1 (FB), R7.2, R8.2
unnamed: IC1.18 (PD0/SCL/INT0), IC3.8 (SCL), IC6.5 (SCL), IC7.5 (SCL), R20.2
unnamed: CON6.3, SW4.C1, SW4.C2
unnamed: C24.2, C25.2, IC6.6 (VS), L2.2
unnamed: IC1.19 (PD1/SDA/INT1), IC3.7 (SDA), IC6.4 (SDA), IC7.4 (SDA), R19.2
unnamed: F2.2, R41.1
unnamed: CON5.5, R27.1, R28.2
unnamed: IC10.3 (D_2), SW4.L2-
unnamed: CON5.10, R21.1
unnamed: CON6.4, SW3.NO1, SW3.NO2
unnamed: CON6.5, SW3.NC1, SW3.NC2
unnamed: CON6.6, SW3.C1, SW3.C2
unnamed: IC1.38 (ADC5/PF5), IC9.5 (G_2)
unnamed: IC1.39 (ADC4/PF4), IC9.2 (G_1)
UVCC: C9.2, D1.2 (A), F1.2, IC1.2 (UVCC), IC1.7 (VBUS)
VCC: C1.2, C2.2, C11.2, C13.2, C14.2, C15.2, C19.2, C20.2, C30.2, C31.2, C32.2, C33.2, CON1.2, CON2.3, D3.1 (K), IC1.14 (VCC), IC1.24 (AVCC), IC1.34 (VCC_1), IC1.44 (AVCC_1), IC3.2 (VCC), IC7.2 (A0), IC8.8 (VCC), L1.1, LED1.2 (A1), LED1.4 (A2), R3.1, R4.2, R7.1, R18.1, R19.1, R20.1, R22.1, R24.1, R25.1, R29.1, R30.1, R34.1, R35.1, R43.1, SW3.L1+, SW3.L2+, SW4.L1+, SW4.L2+
VEXT: CON5.12, D2.2 (A)

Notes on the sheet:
VIN
GND
AIN1+
AIN1-
AIN2+
AIN2-
DIN1+
DIN1-
DIN2+
DIN2-
OUT1_C
OUT1_NC
OUT1_NO
OUT2_NC
OUT2_C
OUT2_NO
VUSB

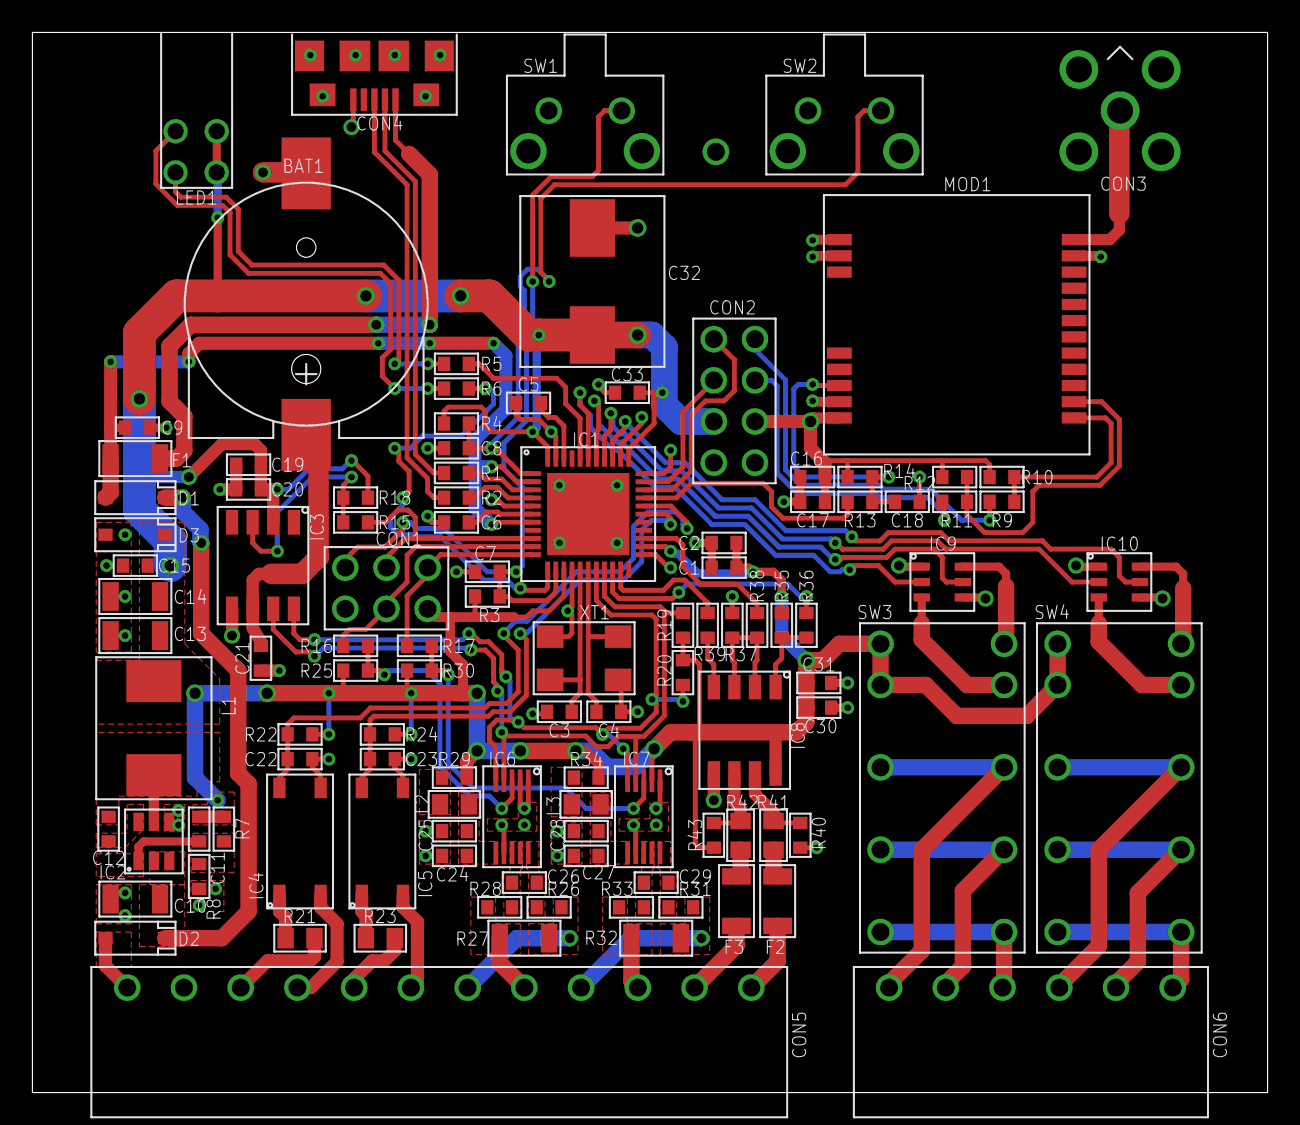
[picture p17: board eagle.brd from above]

Board: 2 copper layers, 76.2 x 65.4 mm, 109 parts (0 on the bottom side), 88 nets.

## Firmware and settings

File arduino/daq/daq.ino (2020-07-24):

// Bootloader: Board SparkFun Pro Micro 3.3V 8MHZ
// sparkfun boards.txt 
// promicro.menu.cpu.8MHzatmega32U4.bootloader.extended_fuses=0xFF
// promicro.build.extra_flags={build.usb_flags} "-DUSB_VERSION=0x210"
// or C:Users/../AppData/Local/Arduino../packages/arduino/hardware/avr/../cores/arduino/USBCore.h 
// line 130: #define USB_VERSION 0x210

#include <avr/wdt.h>
#include <Timer.h>                // https://github.com/JChristensen/Timer
#include <EEPROM.h>
#include <CayenneLPP.h>           // https://github.com/ElectronicCats/CayenneLPP
#include <Wire.h>
#include <INA226.h>               // https://github.com/jarzebski/Arduino-INA226
#include <WebUSB.h>               // https://github.com/webusb/arduino

const uint8_t AN_ALR_PIN[2]       = {12, 6};          // PD6/ADC9, PD7/ADC10
const uint8_t DIG_PIN[2]          = {8, 9};           // PB4/ADC11/PCINT4, PB5/ADC12/PCINT5
const uint8_t LORA_RES_PIN        = 10;               // PB6/ADC13/PCINT6
const uint8_t RANDOM_PIN          = A0;               // PF7/ADC7 
const uint8_t LED_PIN             = A5;               // PF0/ADC0

const uint8_t lru08_dr            = 0;  
const uint8_t lru08_port          = 1;  
const uint8_t lru08_report        = 2;

const uint8_t anu08_enable        = 0;  
const uint8_t anu08_unit          = 1; 

const uint8_t anu16_duration      = 0; 

const uint8_t anf32_in_min        = 0;  
const uint8_t anf32_in_max        = 1;  
const uint8_t anf32_out_min       = 2;  
const uint8_t anf32_out_max       = 3;  
const uint8_t anf32_low           = 4;  
const uint8_t anf32_high          = 5;
const uint8_t anf32_calibrate     = 6;  

const uint8_t dgu08_enable        = 0;  
const uint8_t dgu08_unit          = 1;  
const uint8_t dgu08_debounce      = 2;
const uint8_t dgu08_low_report    = 3;
const uint8_t dgu08_high_report   = 4;

const uint8_t dgu16_duration      = 0;

const uint8_t numAn               = 2;
const uint8_t numDg               = 2;

struct Conf {
  uint8_t   lru08[3];
  uint8_t   anu08[2 * numAn];
  uint16_t  anu16[numAn];
  float     anf32[7 * numAn];
  uint8_t   dgu08[5 * numDg];
  uint16_t  dgu16[numDg];      
};
Conf conf;

float       an[numAn];
uint8_t     dg[numDg];

const uint8_t MID                 = 2;

uint8_t     anPrev[numAn]         = {MID, MID};
uint8_t     dgPrev[numDg]         = {LOW, LOW};

int         anDuration[numAn] = {-1, -1};
int         dgDuration[numDg] = {-1, -1};
int         ledOscForever;

bool isLoraJoin, isUsb, isIntervalReport, isLoraSerial;
String strUsbSerial, strLoraSerial;
const float rshunt = 3.9;

Timer t;
CayenneLPP lpp(51);
INA226 analog;
//WebUSB WebUSBSerial(1 /* https:// */, "emitterpark.github.io/daq");
WebUSB WebUSBSerial(1 /* https:// */, "127.0.0.1:5500");
#define usbSerial WebUSBSerial
#define loraSerial Serial1

void setup() {
  setPin();
  loadConf(); 
  setUsbSerial();   
  setAnalog();
  setDigital();  
  setLoraSerial();
  //t.after(tmrRandom(), setLoraSerial);
  printAll();       
  t.every(conf.lru08[lru08_report] * 1000L * 60, intervalReport);
  ledOscForever = t.oscillate(LED_PIN, 500, HIGH);  
}
void loop() {
  readAnalog();
  readDigital();  
  readLoraSerial();
  if (isUsb) {
    readUsbSerial();
  }  
  t.update();
}
void report() {   
  for (uint8_t ch = 0; ch < numAn; ch++) {
    t.stop(anDuration[ch]);
    anDuration[ch] = -1;
  }
  for (uint8_t ch = 0; ch < numDg; ch++) {
    t.stop(dgDuration[ch]);
    dgDuration[ch] = -1;
  }
  printMsg(F("report")); 
  if (!isLoraJoin) {
    if (isLoraSerial) {
      if(isIntervalReport) {
        isIntervalReport = false;
        resetCpu();    
      }
      return;
    }
  }           
  lpp.reset();  
  for (uint8_t ch = 0; ch < numAn; ch++) {
    const uint8_t _unit = conf.anu08[anu08_unit + ch * (sizeof(conf.anu08) / sizeof(conf.anu08[0])) / numAn];      
    if (_unit == LPP_ANALOG_INPUT) {
      lpp.addAnalogInput(1 + ch, an[ch]);
    } else if (_unit == LPP_LUMINOSITY) {
      lpp.addLuminosity(1 + ch, an[ch]);
    } else if (_unit == LPP_TEMPERATURE) {
      lpp.addTemperature(1 + ch, an[ch]);
    } else if (_unit == LPP_RELATIVE_HUMIDITY) {
      lpp.addRelativeHumidity(1 + ch, an[ch]);
    } else if (_unit == LPP_BAROMETRIC_PRESSURE) {
      lpp.addBarometricPressure(1 + ch, an[ch]);
    } else if (_unit == LPP_VOLTAGE) {
      lpp.addVoltage(1 + ch, an[ch]);
    } else if (_unit == LPP_CURRENT) {
      lpp.addCurrent(1 + ch, an[ch]);
    } else if (_unit == LPP_PERCENTAGE) {
      lpp.addPercentage(1 + ch, an[ch]);
    } else if (_unit == LPP_ALTITUDE) {
      lpp.addAltitude(1 + ch, an[ch]);
    } else if (_unit == LPP_POWER) {
      lpp.addPower(1 + ch, an[ch]);
    } else if (_unit == LPP_DIRECTION) {
      lpp.addDirection(1 + ch, an[ch]);
    } else if (_unit == LPP_DIGITAL_INPUT) {
      lpp.addDigitalInput(1 + ch, an[ch]);
    } else if (_unit == LPP_SWITCH) {
      lpp.addSwitch(1 + ch, an[ch]);
    } else if (_unit == LPP_PRESENCE) {  
      lpp.addPresence(1 + ch, an[ch]);      
    }
  } 
  for (uint8_t ch = 0; ch < numDg; ch++) {
    const uint8_t _unit = conf.dgu08[dgu08_unit + ch * (sizeof(conf.dgu08) / sizeof(conf.dgu08[0])) / numDg];      
    if (_unit == LPP_DIGITAL_INPUT) {
      lpp.addDigitalInput(3 + ch, dg[ch]);
    } else if (_unit == LPP_SWITCH) {
      lpp.addSwitch(3 + ch, dg[ch]);
    } else if (_unit == LPP_PRESENCE) {
      lpp.addPresence(3 + ch, dg[ch]);
    }
  }    
  loraSerial.print("at+send=lora:" + String(conf.lru08[lru08_port]) + ':'); 
  loraSerial.println(lppGetBuffer());       
}
void readLoraSerial() { 
  while (loraSerial.available()) {    
    const char chr = (char)loraSerial.read();    
    strLoraSerial += chr;
    if (chr == '\n') {
      strLoraSerial.trim();      
      if (strLoraSerial.endsWith(F("Join Success"))) {        
        delay(10);         
        loraSerial.print(F("at+set_config=lora:dr:")); 
        loraSerial.println(conf.lru08[lru08_dr]); 
      } else if (strLoraSerial.endsWith(F("JOIN_FAIL 99"))) {
        isLoraJoin = false;
        printMsg(F("xjoinlrwCould not Join to Network"));
      } else if (strLoraSerial.indexOf(F("Join retry")) >= 0) {
        isLoraJoin = false;
        t.stop(ledOscForever);
        ledOscForever = t.oscillate(LED_PIN, 500, HIGH);
        printMsg(F("xjoinlrwJoining to Network .."));
      } else if (strLoraSerial.indexOf(F("NO_NETWORK")) >= 0) {
        isLoraJoin = false;
        printMsg(F("xjoinlrwCould not Join to Network")); 
      } else if (strLoraSerial.indexOf(F("configure DR")) >= 0) {
        isLoraJoin = true;         
        t.stop(ledOscForever);        
        digitalWrite(LED_PIN, LOW);              
        printMsg(F("xjoinlrwJoin Success"));              
      }
      if (isUsb) {
        usbSerial.println(strLoraSerial); 
        usbSerial.flush();
      }           
      strLoraSerial = "";
    }
  }
}
void readUsbSerial() {
  while (usbSerial && usbSerial.available()) {    
    const char chr = (char)usbSerial.read();
    strUsbSerial += chr;
    if (chr == '\n') {
      strUsbSerial.trim();
      const uint8_t num = strUsbSerial.substring(6, 8).toInt();
      const uint16_t valInt = strUsbSerial.substring(8).toInt();
      const float valFloat = strUsbSerial.substring(8).toFloat();       
      if (strUsbSerial.startsWith(F("at"))) {
        loraSerial.println(strUsbSerial);      
      } else if (strUsbSerial.startsWith(F("xlru08"))) {
        conf.lru08[num] = (uint8_t)valInt;
      } else if (strUsbSerial.startsWith(F("xanu08"))) {
        conf.anu08[num] = (uint8_t)valInt;
      } else if (strUsbSerial.startsWith(F("xanu16"))) {
        conf.anu16[num] = (uint16_t)valInt;
      } else if (strUsbSerial.startsWith(F("xanf32"))) {
        conf.anf32[num] = valFloat;
      } else if (strUsbSerial.startsWith(F("xdgu08"))) {
        conf.dgu08[num] = (uint8_t)valInt;
      } else if (strUsbSerial.startsWith(F("xdgu16"))) {
        conf.dgu16[num] = (uint16_t)valInt;
      } else if (strUsbSerial.startsWith(F("xsave"))) {
        EEPROM.put(0, conf);
        resetCpu();      
      } else if (strUsbSerial.startsWith(F("xreport"))) {
        report();       
      }
      strUsbSerial = "";
    }
  }   
}
void readAnalog() {      
  for (uint8_t ch = 0; ch < numAn; ch++) {
    const uint8_t _enable = anu08_enable + ch * (sizeof(conf.anu08) / sizeof(conf.anu08[0])) / numAn; 
    if (conf.anu08[_enable]) {   
      if (!digitalRead(AN_ALR_PIN[ch])) {        
        analog.begin(0x40 + ch);
        an[ch] = analog.readShuntVoltage();
        if (analog.isAlert()); 
        while (!digitalRead(AN_ALR_PIN[ch])) {          
        }       
        const uint8_t _in_min = anf32_in_min + ch * (sizeof(conf.anf32) / sizeof(conf.anf32[0])) / numAn;
        const uint8_t _in_max = anf32_in_max + ch * (sizeof(conf.anf32) / sizeof(conf.anf32[0])) / numAn;
        const uint8_t _out_min = anf32_out_min + ch * (sizeof(conf.anf32) / sizeof(conf.anf32[0])) / numAn;
        const uint8_t _out_max = anf32_out_max + ch * (sizeof(conf.anf32) / sizeof(conf.anf32[0])) / numAn;
        const uint8_t _calibrate = anf32_calibrate + ch * (sizeof(conf.anf32) / sizeof(conf.anf32[0])) / numAn;
        an[ch] *= 1000L;
        an[ch] /= rshunt;
        an[ch] = (an[ch] - conf.anf32[_in_min]) * (conf.anf32[_out_max] - conf.anf32[_out_min]) / (conf.anf32[_in_max] - conf.anf32[_in_min]) + conf.anf32[_out_min];      
        //an[ch] *= (1.0 + conf.anf32[_calibrate]);
        //an[ch] += 0.005;        
        //an[ch] = round(an[ch]*100.0)/100.0;
        fetchAnalog(ch);
        isAnalogReport(ch);
      }      
    }                    
  }    
}
void fetchAnalog(const uint8_t ch) { 
  if (!isUsb) {
    return;
  }
  String str;  
  usbSerial.print(F("xanval"));    
  str = '0' + String(ch);
  usbSerial.print(str.substring(str.length() - 2));    
  usbSerial.println(an[ch], 2);
  usbSerial.flush();      
}
void isAnalogReport(const uint8_t ch) {       
  const uint8_t _low = anf32_low + ch * (sizeof(conf.anf32) / sizeof(conf.anf32[0])) / numAn; 
  const uint8_t _high = anf32_high + ch * (sizeof(conf.anf32) / sizeof(conf.anf32[0])) / numAn;  
  const uint8_t _duration = anu16_duration + ch * (sizeof(conf.anu16) / sizeof(conf.anu16[0])) / numAn;    
  if (an[ch] > conf.anf32[_low] && an[ch] < conf.anf32[_high]) {    
    if (anPrev[ch] != MID) {
      anPrev[ch] = MID;                 
      if (anDuration[ch] > 0) {
        t.stop(anDuration[ch]);
        anDuration[ch] = -1;
        return;
      }              
      t.stop(anDuration[ch]);
      anDuration[ch] = t.after(conf.anu16[_duration] * 1000L, report);                 
    }                  
  } else if (an[ch] <= conf.anf32[_low]) {    
    if (anPrev[ch] != LOW) {
      anPrev[ch] = LOW;                      
      if (anDuration[ch] > 0) {
        t.stop(anDuration[ch]);
        anDuration[ch] = -1;
        return; 
      }      
      t.stop(anDuration[ch]);
      anDuration[ch] = t.after(conf.anu16[_duration] * 1000L, report);
    }                  
  } else if (an[ch] >= conf.anf32[_high]) {     
    if (anPrev[ch] != HIGH) {
      anPrev[ch] = HIGH;                 
      if (anDuration[ch] > 0) {
        t.stop(anDuration[ch]);
        anDuration[ch] = -1;
        return;
      }      
      t.stop(anDuration[ch]);
      anDuration[ch] = t.after(conf.anu16[_duration] * 1000L, report);
    }    
  }  
}
void readDigital() {
  for (uint8_t ch = 0; ch < numDg; ch++) {  
    const uint8_t _enable = dgu08_enable + ch * (sizeof(conf.dgu08) / sizeof(conf.dgu08[0])) / numDg;
    if (conf.dgu08[_enable]) {
      dg[ch] = !digitalRead(DIG_PIN[ch]);
      if (dg[ch] != dgPrev[ch]) {        
        const uint8_t _debounce = dgu08_debounce + ch * (sizeof(conf.dgu08) / sizeof(conf.dgu08[0])) / numDg;        
        delay(conf.dgu08[_debounce]);     
        if (dg[ch] == !digitalRead(DIG_PIN[ch])) {
          isDigitalReport(ch);
        } else {
          dg[ch] = !digitalRead(DIG_PIN[ch]);           
        }
      }                       
    }    
  }
}
void fetchDigital(const uint8_t ch) { 
  if (!isUsb) {
    return;
  }
  String str;
  usbSerial.print(F("xdgval"));    
  str = '0' + String(ch);
  usbSerial.print(str.substring(str.length() - 2));    
  usbSerial.println(dg[ch]);
  usbSerial.flush();       
}
void isDigitalReport(const uint8_t ch) {
  const uint8_t _low_report = dgu08_low_report + ch * (sizeof(conf.dgu08) / sizeof(conf.dgu08[0])) / numDg; 
  const uint8_t _high_report = dgu08_high_report + ch * (sizeof(conf.dgu08) / sizeof(conf.dgu08[0])) / numDg;
  const uint8_t _duration = dgu16_duration + ch * (sizeof(conf.dgu16) / sizeof(conf.dgu16[0])) / numDg;       
  if (dg[ch] != dgPrev[ch]) {
    fetchDigital(ch);
    if (dg[ch] == LOW) {
      dgPrev[ch] = LOW;                            
      if (dgDuration[ch] > 0) {
        t.stop(dgDuration[ch]);
        dgDuration[ch] = -1;        
        return; 
      }       
      if (conf.dgu08[_low_report]) {                
        t.stop(dgDuration[ch]);        
        dgDuration[ch] = t.after(conf.dgu16[_duration] * 1000L, report);                               
      }          
    } else if (dg[ch] == HIGH) { 
      dgPrev[ch] = HIGH;                       
      if (dgDuration[ch] > 0) {
        t.stop(dgDuration[ch]);
        dgDuration[ch] = -1;        
        return;
      }            
      if (conf.dgu08[_high_report]) {                
        t.stop(dgDuration[ch]);        
        dgDuration[ch] = t.after(conf.dgu16[_duration] * 1000L, report);                                  
      }       
    }
  }         
}
void loadConf() {
  EEPROM.get(0, conf);  
}
void setPin() {
  for (uint8_t ch = 0; ch < 2; ch++) {
    pinMode(AN_ALR_PIN[ch], INPUT);
    pinMode(DIG_PIN[ch], INPUT);
  }
  pinMode(LORA_RES_PIN, OUTPUT);
  pinMode(LED_PIN, OUTPUT);
  digitalWrite(LORA_RES_PIN, LOW);
  digitalWrite(LED_PIN, HIGH);  
}
void setAnalog() {
  for (uint8_t ch = 0; ch < numAn; ch++) {       
    analog.begin(0x40 + ch);
    analog.configure(INA226_AVERAGES_1024, INA226_BUS_CONV_TIME_140US, INA226_SHUNT_CONV_TIME_1100US, INA226_MODE_SHUNT_CONT);
    analog.calibrate(3.9, 0.020);
    analog.readShuntVoltage();
    analog.enableConversionReadyAlert(); 
    if (analog.isAlert());              
  } 
}
void setDigital() {
  for (uint8_t ch = 0; ch < numDg; ch++) {
    dg[ch] = !digitalRead(DIG_PIN[ch]);
    dgPrev[ch] = dg[ch];    
  }  
}
void setLoraSerial() {
  while (!loraSerial) {    
  }
  loraSerial.begin(115200);    
  delay(10);
  pinMode(LORA_RES_PIN, INPUT);
  delay(1000);
  isLoraSerial = true;
  loraSerial.println("at+version");    
}
void setUsbSerial() {
  if (USBSTA >> VBUS & 1) {          
    while (!usbSerial) {      
    }
  }  
  usbSerial.begin(9600);  
  usbSerial.flush(); 
  isUsb = true;   
}
void printAll() {
  printChFetch();
  printMsg(F("xdeviceeLoraWAN Wireless DAQ"));   
  printMsg(F("xversionFirmware 1.0.1"));
  printChConf();
  printLoraConf();
  printLoraKeys();
  printMsg(F("xjoinlrwJoining to Network .."));
}
void printMsg(String msg) {
  if (!isUsb) {
    return;
  }
  usbSerial.println(msg);
  usbSerial.flush();
}
void printChFetch() {
  if (!isUsb) {
    return;
  }
  for (uint8_t ch = 0; ch < numAn; ch++) {
    fetchAnalog(ch);       
  }
  for (uint8_t ch = 0; ch < numDg; ch++) {
    fetchDigital(ch);       
  }
}
void printChConf() {
  if (!isUsb) {
    return;
  }
  String str;
  for (uint8_t i = 0; i < (sizeof(conf.anu08) / sizeof(conf.anu08[0])); i++) {
    usbSerial.print(F("xanu08"));    
    str = '0' + String(i);
    usbSerial.print(str.substring(str.length() - 2));    
    usbSerial.println(conf.anu08[i]);
    usbSerial.flush();    
  }
  for (uint8_t i = 0; i < (sizeof(conf.anu16) / sizeof(conf.anu16[0])); i++) {
    usbSerial.print(F("xanu16"));    
    str = '0' + String(i);
    usbSerial.print(str.substring(str.length() - 2));    
    usbSerial.println(conf.anu16[i]);
    usbSerial.flush();    
  }
  for (uint8_t i = 0; i < (sizeof(conf.anf32) / sizeof(conf.anf32[0])); i++) {
    usbSerial.print(F("xanf32"));    
    str = '0' + String(i);
    usbSerial.print(str.substring(str.length() - 2));    
    usbSerial.println(conf.anf32[i], 2); 
    usbSerial.flush();   
  }
  for (uint8_t i = 0; i < (sizeof(conf.dgu08) / sizeof(conf.dgu08[0])); i++) {
    usbSerial.print(F("xdgu08"));    
    str = '0' + String(i);
    usbSerial.print(str.substring(str.length() - 2));    
    usbSerial.println(conf.dgu08[i]);
    usbSerial.flush();    
  }
  for (uint8_t i = 0; i < (sizeof(conf.dgu16) / sizeof(conf.dgu16[0])); i++) {
    usbSerial.print(F("xdgu16"));    
    str = '0' + String(i);
    usbSerial.print(str.substring(str.length() - 2));    
    usbSerial.println(conf.dgu16[i]);
    usbSerial.flush();    
  }    
}
void printLoraConf() {
  if (!isUsb) {
    return;
  }
  String str;
  for (uint8_t i = 0; i < sizeof(conf.lru08); i++) {    
    usbSerial.print(F("xlru08"));    
    str = '0' + String(i);
    usbSerial.print(str.substring(str.length() - 2));    
    usbSerial.println(conf.lru08[i]);
    usbSerial.flush();    
  } 
}
void printLoraKeys() {
  if (!isUsb) {
    return;
  }
  delay(10);         
  loraSerial.println(F("at+get_config=lora:status")); 
}
void intervalReport() {
 isIntervalReport = true;
 report(); 
}
unsigned long tmrRandom() {
  randomSeed(analogRead(RANDOM_PIN));
  return random(24) * 5000L + 10000L;   // min 10sec, max 2min + 10sec   
}
void resetCpu() {
  wdt_enable(WDTO_15MS);
  while(true);  
}
String lppGetBuffer() {
  String str;
  for(uint8_t i = 0; i < lpp.getSize(); i++){    
    if (lpp.getBuffer()[i] < 16) {
      str += '0';       
    }
    str += String(lpp.getBuffer()[i], HEX);
    str.toUpperCase();        
  }
  return str;
}

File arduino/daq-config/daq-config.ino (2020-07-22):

#include <EEPROM.h>

const uint8_t numAn                     = 2;
const uint8_t numDg                     = 2;

struct Conf {
  const uint8_t   lru08[3]              = {2,90,5};
  const uint8_t   anu08[2 * numAn]      = {1,2,1,2};
  const uint16_t  anu16[numAn]          = {1,1};
  const float     anf32[7 * numAn]      = {4,20,4,20,11,13,0,4,20,4,20,11,13,0};
  const uint8_t   dgu08[5 * numDg]      = {1,0,20,1,1,1,0,20,1,1};
  const uint16_t  dgu16[numDg]          = {1,1};
};

Conf conf;

void setup() {
  for (int i = 0 ; i < EEPROM.length() ; i++) {
    EEPROM.write(i, 0);
  }
  EEPROM.put(0, conf);
}

void loop() {
}
